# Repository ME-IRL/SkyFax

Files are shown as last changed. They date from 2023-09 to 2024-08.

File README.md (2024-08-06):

# SkyFax Modems

Fax and data modems built around Skyworks's [ISOModem chips](https://www.skyworksinc.com/en/Products/Modems-and-DAAs).

Current functional version is 4.1 (see 3.0 below):

Version 4.1 Assembled

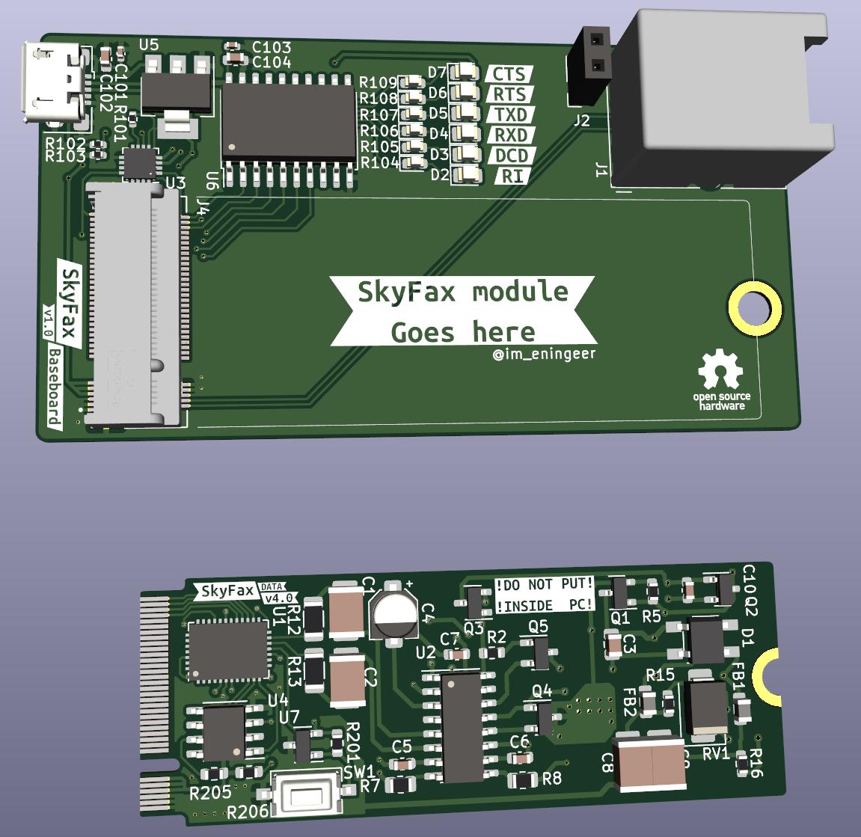
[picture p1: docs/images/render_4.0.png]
Revision 4.0 KiCad 3D Render


## Case

I've also designed and printed a case to go with it. The STL files can be found under [/case](/case). Or on [OnShape](https://cad.onshape.com/documents/ec3c126b0fcf528ada2a864d/w/a2689da35195e5fe9917eb13/e/6bc9b2e75f28a1d3ae68eb94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).

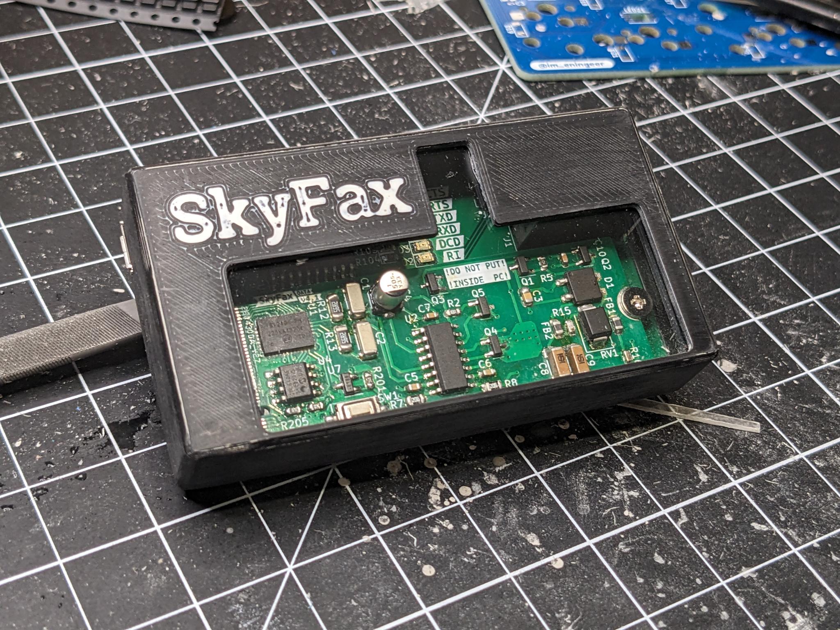
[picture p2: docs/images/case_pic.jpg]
case


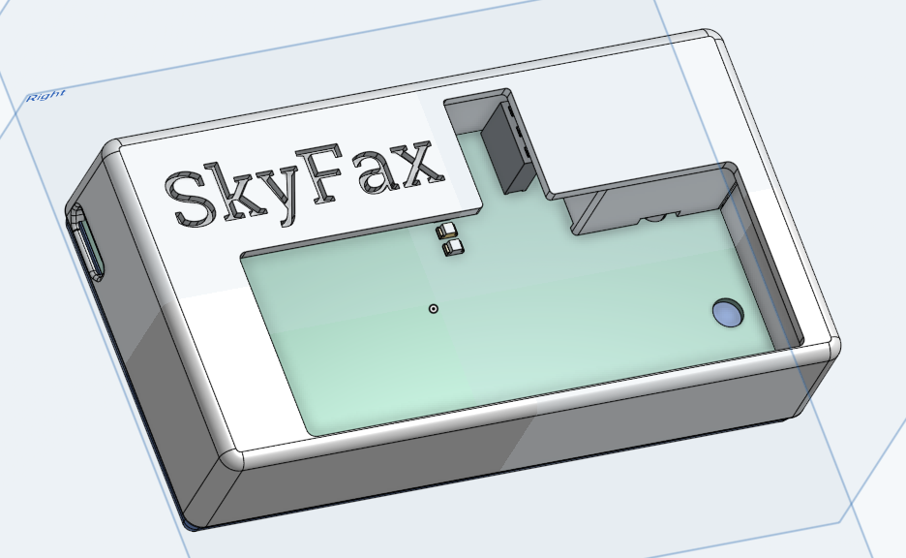
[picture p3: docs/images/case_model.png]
model


Version 3.0:

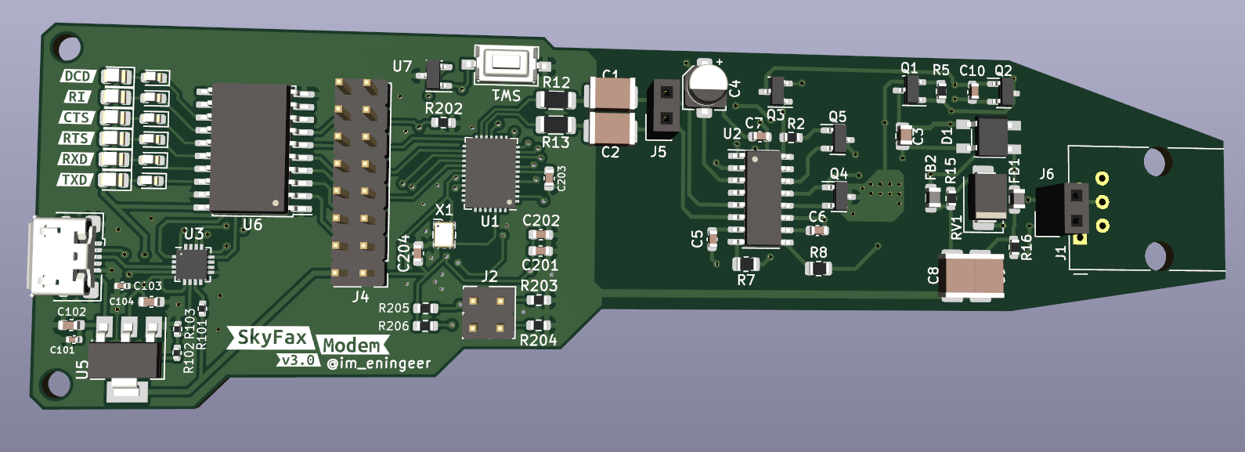
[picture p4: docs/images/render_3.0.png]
Revision 3.0 KiCad 3D Render


## Simple Line Simulator

If you don't have access to a working landline or a proper telephone line simulator two modems can be connected back to back directly.

There are [this](https://tldp.org/HOWTO/Modem-HOWTO-26.html) and [this](https://mattfife.com/?p=4765) pages, but I have found this circuit to work for me:

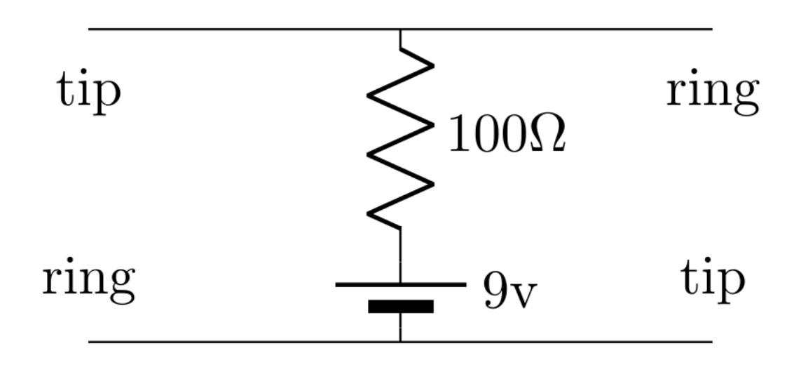
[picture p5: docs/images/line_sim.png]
Simple line simulator


The voltage and resistance can be tweaked to provide ~20mA of current with the modem/phone off-hook.

If you'd like the schematic or just have a PCB made for the line simulator, check out the [LineSim](/LineSim) project included in this repo.

Once hooked up, you want to disable the dialtone detection with the command `ATX3`. Then you can just dial with `ATDT` on one modem and answer with `ATA` on the other.

See [AN93](/docs/AN93.pdf) section 5.4 for details on all the AT commands supported.

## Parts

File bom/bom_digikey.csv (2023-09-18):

Reference | Value | Footprint | DIGIKEY | Qty
C1, C2 | 33pF | FaxCam:C_1808 | 732-8853520100071CT-ND | 2
C3 | 10nF | Capacitor_SMD:C_0805_2012Metric | 2679-C0805X7R251-103KNE-CT-ND | 1
C4 | 1uF | Capacitor_SMD:CP_Elec_4x3 | PCE3912CT-ND | 1
C5, C6, C102, C104, C201, C202, C204 | 0.1uF | Capacitor_SMD:C_0603_1608Metric | 2679-C0603X7R160-104MNE-CT-ND | 7
C7 | 2.7nF | Capacitor_SMD:C_0603_1608Metric | 2679-C0603X7R500-272MNE-CT-ND | 1
C8, C9 | 680pF | FaxCam:C_1808 | 4587-SCC1808X681K502TGCT-ND | 2
C10 | 0.01uF | Capacitor_SMD:C_0603_1608Metric | 2679-C0603X7R160-103MNE-CT-ND | 1
C101, C103 | 4.7uF | Capacitor_SMD:C_0402_1005Metric | 1276-1482-1-ND | 2
C203 | 0.22uF | Capacitor_SMD:C_0603_1608Metric | 1292-1420-1-ND | 1
D1 | HDS10M | FaxCam:Diodes_Inc_4-SMD | HDS10M-13DICT-ND | 1
D2-D7 | LED | LED_SMD:LED_0805_2012Metric | 160-1427-1-ND | 6
FB1, FB2 | FerriteBead_Small | Inductor_SMD:L_0805_2012Metric | 490-1040-1-ND | 2
J1 | RJ11/12 | Connector_RJ:RJ12_Amphenol_54601 | 609-5080-ND | 1
J2 | Audio | Connector_PinSocket_2.54mm:PinSocket_1x02_P2.54mm_Vertical |  | 1
J3 | USB_B_Micro | Connector_USB:USB_Micro-B_Amphenol_10118193-0001LF_Horizontal | 609-4616-1-ND | 1
J4 | M.2_B_Connector | SkyFax:AMPHENOL_MDT420B01001_2260 | MDT420B01001CT-ND | 1
J7 | M.2_B_Edge | SkyFax:M.2-B-KEY_2260 |  | 1
Q1, Q3 | Q_NPN_BEC | Package_TO_SOT_SMD:SOT-23-3 | MMBTA42LT1GOSCT-ND | 2
Q2 | Q_PNP_BEC | Package_TO_SOT_SMD:SOT-23-3 | MMBTA92LT1GOSCT-ND | 1
Q4, Q5 | Q_NPN_BEC | Package_TO_SOT_SMD:SOT-23-3 | MMBTA06LT1GOSCT-ND | 2
R1 | 1.07k | Resistor_SMD:R_2010_5025Metric | 13-RC2010FK-071K07LCT-ND | 1
R2 | 150 | Resistor_SMD:R_0603_1608Metric | 311-150HRCT-ND | 1
R3 | 3.65k | Resistor_SMD:R_2010_5025Metric | 13-RC2010FK-073K65LCT-ND | 1
R4 | 2.49k | Resistor_SMD:R_2010_5025Metric | 738-RMCF2010FT2K49CT-ND | 1
R5, R6 | 100k | Resistor_SMD:R_0603_1608Metric | A130103CT-ND | 2
R7, R8 | 20M | Resistor_SMD:R_0805_2012Metric | 13-RC0805JR-0720MLCT-ND | 2
R9 | 1M | Resistor_SMD:R_0603_1608Metric | A121559CT-ND | 1
R10 | 536 | Resistor_SMD:R_1210_3225Metric | 541-536AACT-ND | 1
R11 | 73.2 | Resistor_SMD:R_2010_5025Metric | 13-RC2010FK-0773R2LCT-ND | 1
R12, R13 | 56.2 | Resistor_SMD:R_1206_3216Metric | RNCP1206FTD56R2CT-ND | 2
R15, R16 | 0 | Resistor_SMD:R_0603_1608Metric | 36-5110CT-ND | 2
R101 | 1k | Resistor_SMD:R_0402_1005Metric | 311-1.0KJRCT-ND | 1
R102 | 22.1k | Resistor_SMD:R_0402_1005Metric | 311-22.1KLRCT-ND | 1
R103 | 47.5k | Resistor_SMD:R_0402_1005Metric | 311-47.5KLRCT-ND | 1
R104-R109 | 220 | LED_SMD:LED_0603_1608Metric | A130087CT-ND | 6
R201, R202, R205, R206 | 10k | Resistor_SMD:R_0603_1608Metric | RNCP0603FTD10K0CT-ND | 4
RV1 | ~ | Diode_SMD:D_SMB | P3100SBLRPCT-ND | 1
SW1 | SW_Push | Button_Switch_SMD:SW_Tactile_SPST_NO_Straight_CK_PTS636Sx25SMTRLFS | CKN12322-1-ND | 1
U1 | Si2494-A-FM | Package_DFN_QFN:QFN-38-1EP_5x7mm_P0.5mm_EP3.15x5.15mm | SI2494-A-FM-ND | 1
U2 | Si3018 | Package_SO:SOIC-16_3.9x9.9mm_P1.27mm | 336-4140-2-ND | 1
U3 | CP2102N-Axx-xQFN20 | Package_DFN_QFN:SiliconLabs_QFN-20-1EP_3x3mm_P0.5mm_EP1.8x1.8mm | 336-5886-1-ND | 1
U4 | 25LC640AT-E/SN | Package_SO:SOIC-8_3.9x4.9mm_P1.27mm | 25LC640AT-E/SNCT-ND | 1
U5 | AZ1117-3.3 | Package_TO_SOT_SMD:SOT-223-3_TabPin2 | AZ1117IH-3.3TRG1DICT-ND | 1
U6 | 74LCX541 | Package_SO:SOIC-20W_7.5x12.8mm_P1.27mm | 74LCX541WMXCT-ND | 1
U7 | DS1818 | Package_TO_SOT_SMD:SOT-23-3 | DS1818R-10+CT-ND | 1
X1 | ECS-2520MV-xxx-xx | Oscillator:Oscillator_SMD_ECS_2520MV-xxx-xx-4Pin_2.5x2.0mm | XC3186CT-ND | 1
Z1 | D_Zener | Diode_SMD:D_SOD-123 | BZT52C43-FDICT-ND | 1

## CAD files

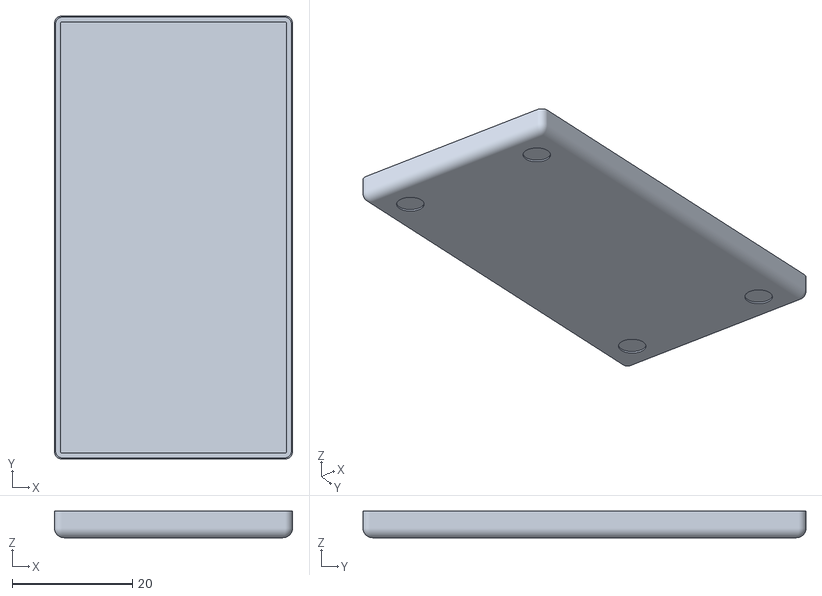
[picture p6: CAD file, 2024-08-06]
case/bottom.stl
39.5 x 73.6 x 4.40

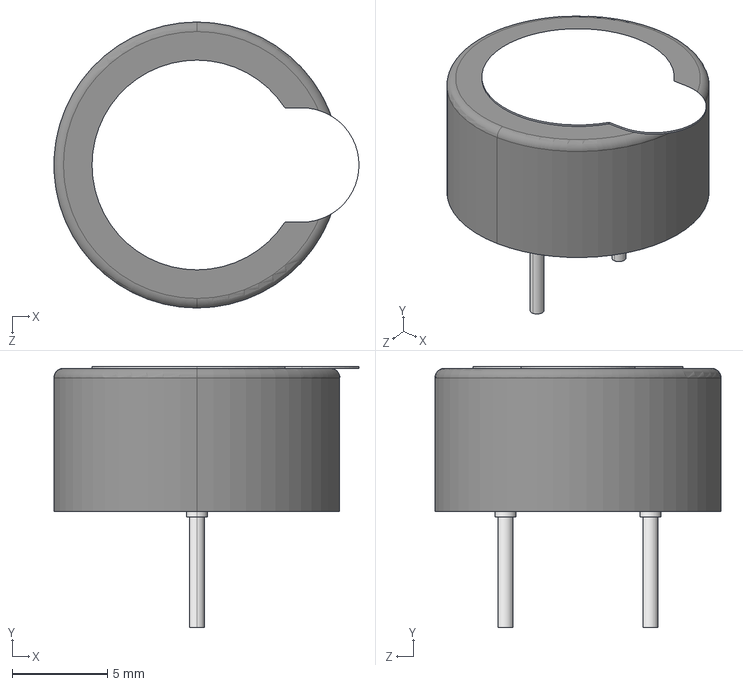
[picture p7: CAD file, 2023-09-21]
SoundCard/3dmodels/CUI_DEVICES_CVS-1508.step
16.0 x 13.7 x 15.0 mm

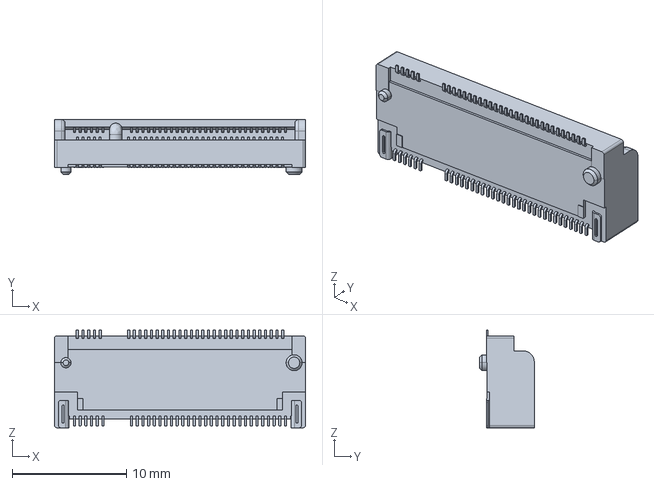
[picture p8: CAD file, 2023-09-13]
3dmodel/mdt420b0x001_c3d.stp
22.0 x 4.80 x 8.55 mm

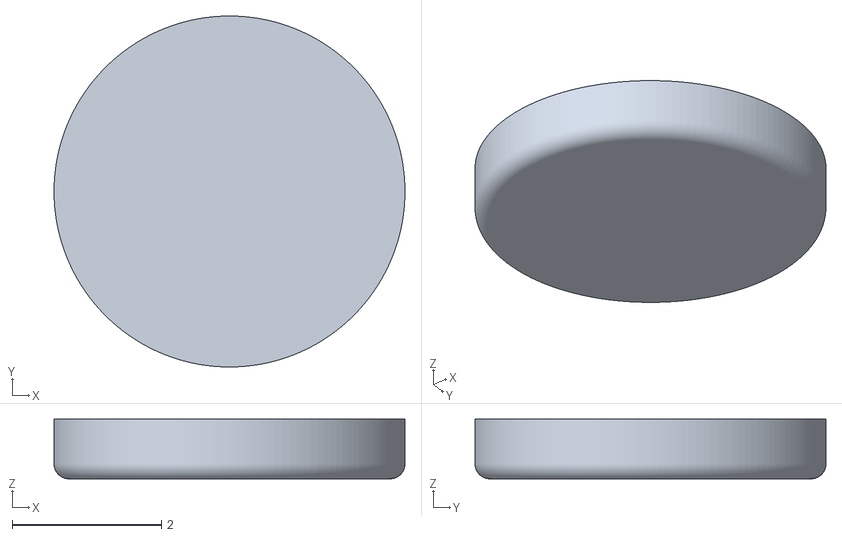
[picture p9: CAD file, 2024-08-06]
case/feet.stl
4.70 x 4.70 x 0.8

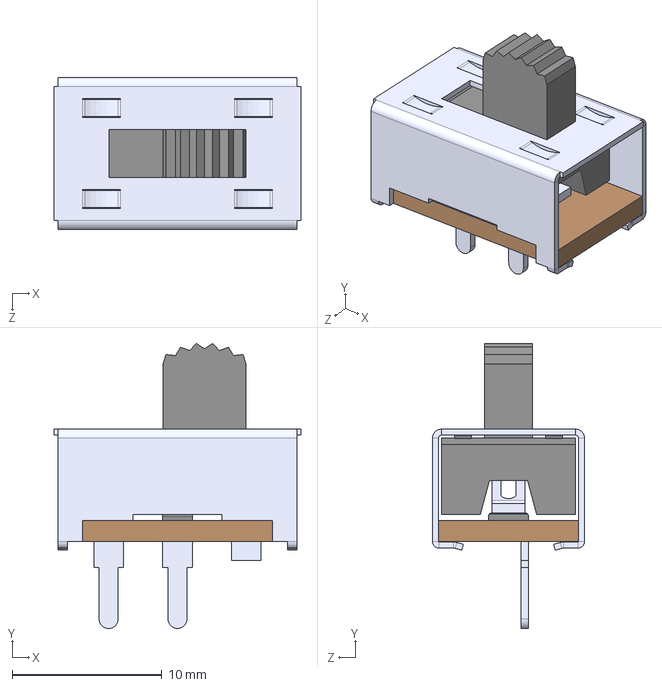
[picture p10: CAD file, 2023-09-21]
LineSim/3dmodels/GF-123-0054.step
16.5 x 19.0 x 10.2 mm

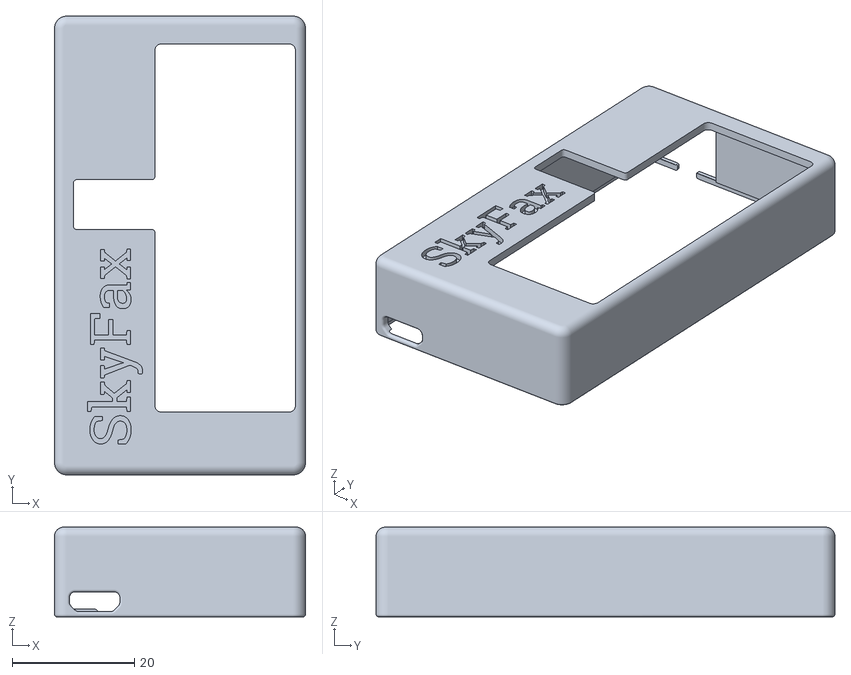
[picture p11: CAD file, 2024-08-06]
case/top.stl
41.1 x 75.2 x 14.7

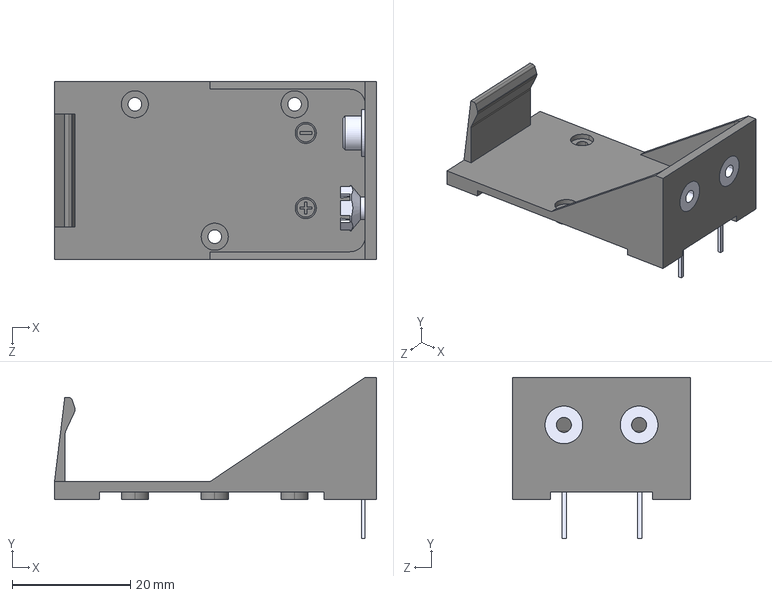
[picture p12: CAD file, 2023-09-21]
LineSim/3dmodels/BH9VPC.step
54.4 x 27.2 x 30.0 mm

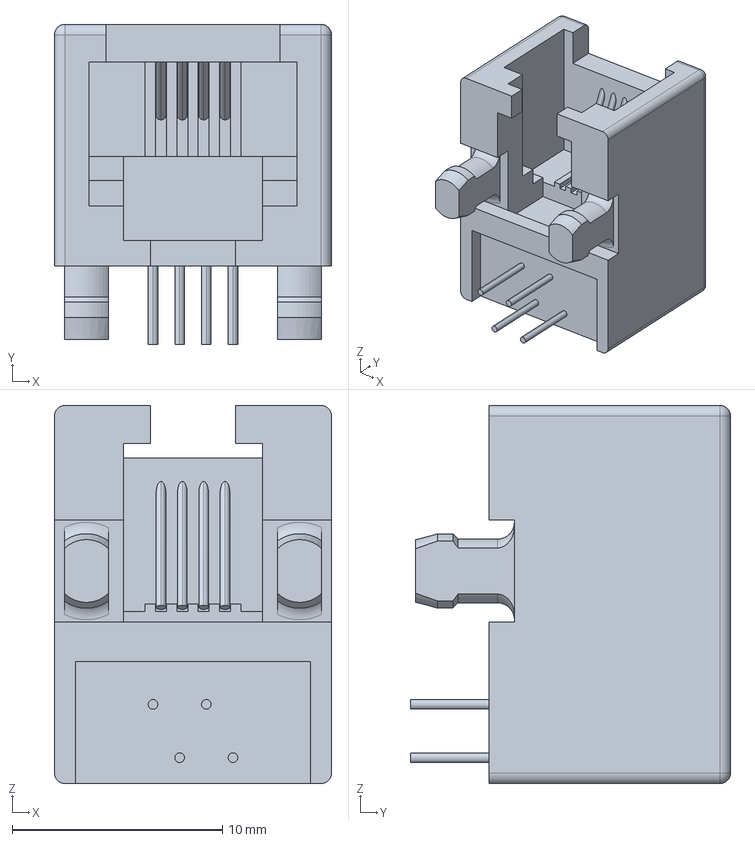
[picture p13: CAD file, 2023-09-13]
3dmodel/54601-906002WPLFc.stp
13.2 x 15.2 x 18.0 mm

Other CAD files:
LineSim/3dmodels/54601-906001.step
SoundCard/3dmodels/CUI_DEVICES_CVS-1508.STL

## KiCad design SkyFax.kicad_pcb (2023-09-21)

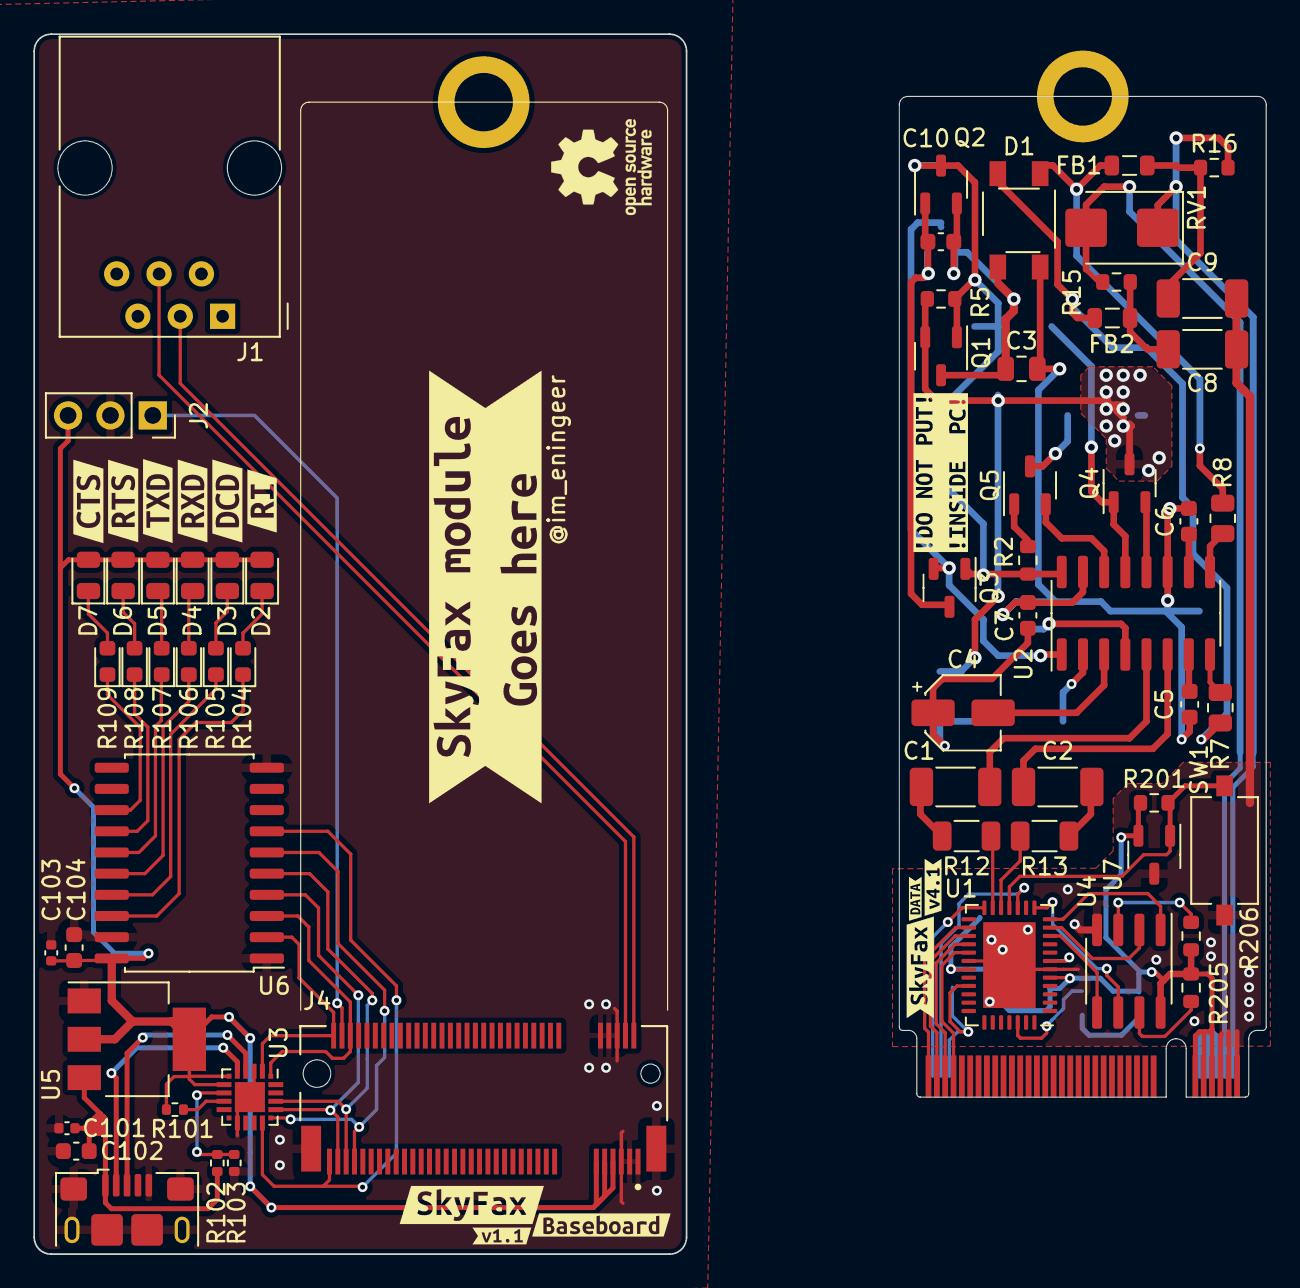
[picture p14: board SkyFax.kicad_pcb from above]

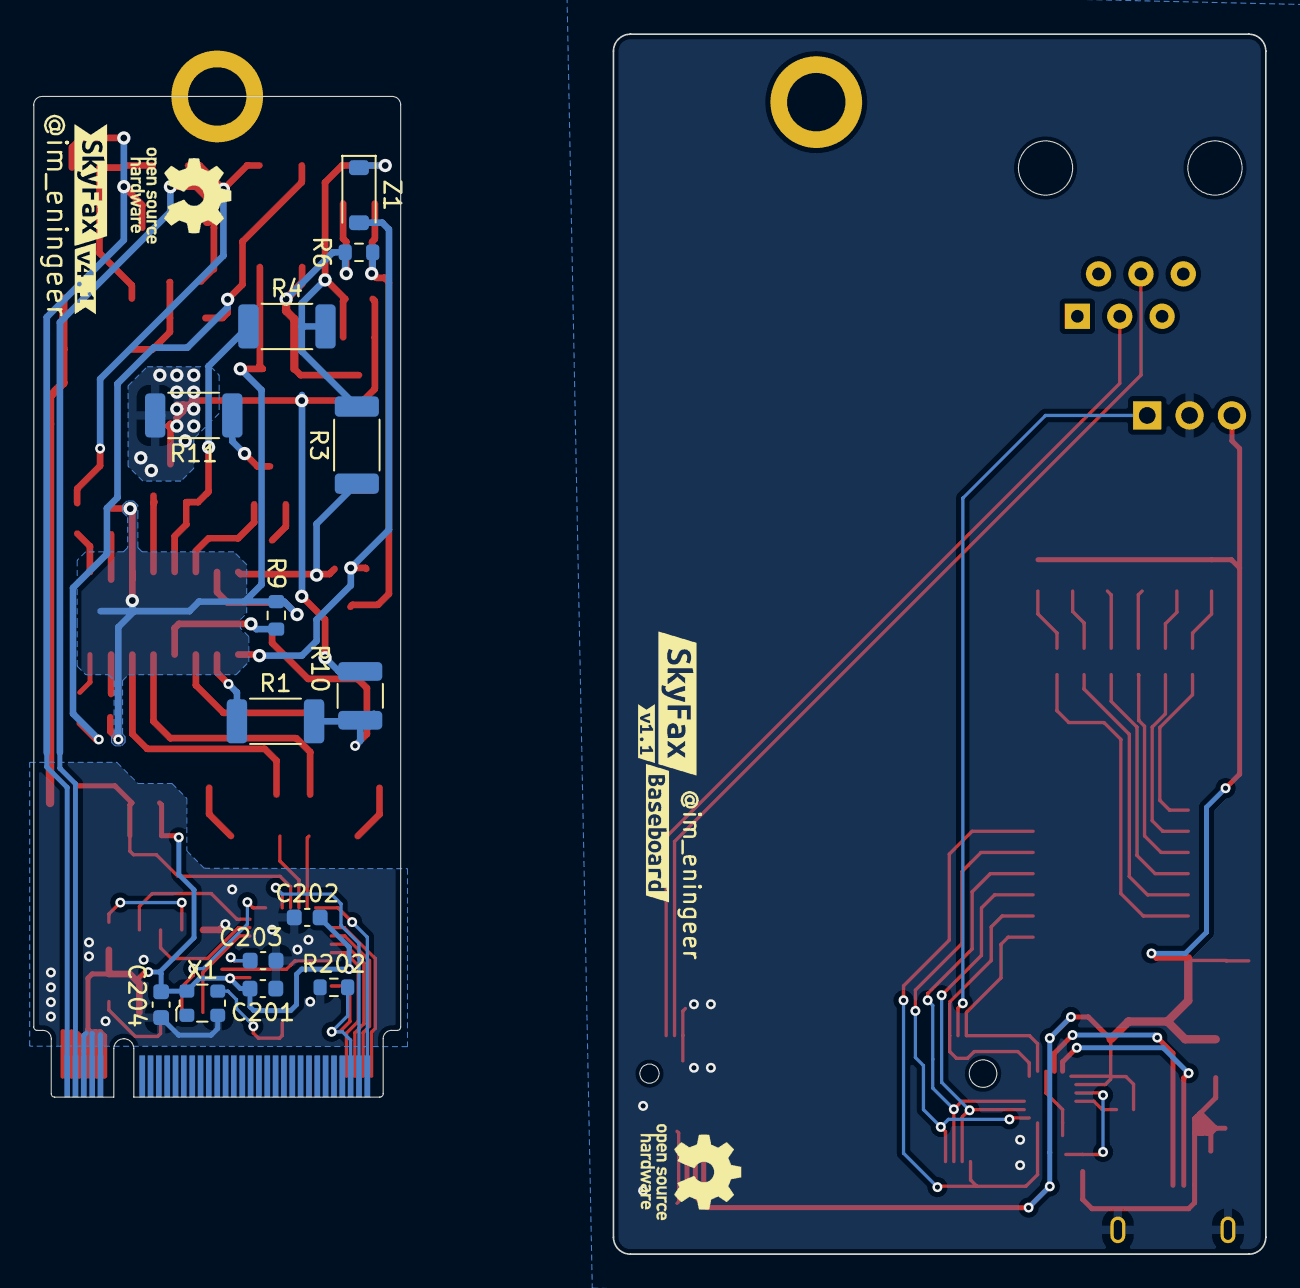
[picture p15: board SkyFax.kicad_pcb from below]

Board: 2 copper layers, 73.9 x 73.2 mm, 95 parts (19 on the bottom side), 76 nets.

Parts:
C1, C2: 33pF; C_1808
C3: 10nF; C_0805_2012Metric
C4: 1uF; CP_Elec_4x3
C5, C6, C102, C104, C201, C202, C204: 0.1uF; C_0603_1608Metric
C7: 2.7nF; C_0603_1608Metric
C8, C9: 680pF; C_1808
C10: 0.01uF; C_0603_1608Metric
C101, C103: 4.7uF; C_0402_1005Metric
C203: 0.22uF; C_0603_1608Metric
D1: HDS10M; Diodes_Inc_4-SMD
D2, D3, D4, D5, D6, D7: LED; LED_0805_2012Metric
FB1, FB2: FerriteBead_Small; L_0805_2012Metric
J1: RJ11/12; RJ12_Amphenol_54601
J2: Audio; PinSocket_1x03_P2.54mm_Vertical
J3: USB_B_Micro; USB_Micro-B_Amphenol_10118193-0001LF_Horizontal
J4: M.2_B_Connector; AMPHENOL_MDT420B01001_2260
J7: M.2_B_Edge; M.2-B-KEY_2260
Q1, Q3, Q4, Q5: Q_NPN_BEC; SOT-23-3
Q2: Q_PNP_BEC; SOT-23-3
R1: 1.07k; R_2010_5025Metric
R2: 150; R_0603_1608Metric
R3: 3.65k; R_2010_5025Metric
R4: 2.49k; R_2010_5025Metric
R5, R6: 100k; R_0603_1608Metric
R7, R8: 20M; R_0805_2012Metric
R9: 1M; R_0603_1608Metric
R10: 536; R_1210_3225Metric
R11: 73.2; R_2010_5025Metric
R12, R13: 56.2; R_1206_3216Metric
R15, R16: 0; R_0603_1608Metric
R101: 1k; R_0402_1005Metric
R102: 22.1k; R_0402_1005Metric
R103: 47.5k; R_0402_1005Metric
R104, R105, R106, R107, R108, R109: 220; LED_0603_1608Metric
R201, R202, R205, R206: 10k; R_0603_1608Metric
RV1: D_SMB
SW1: SW_Push; SW_Tactile_SPST_NO_Straight_CK_PTS636Sx25SMTRLFS
U1: Si2494-A-FM; QFN-38-1EP_5x7mm_P0.5mm_EP3.15x5.15mm
U2: Si3018; SOIC-16_3.9x9.9mm_P1.27mm
U3: CP2102N-Axx-xQFN20; SiliconLabs_QFN-20-1EP_3x3mm_P0.5mm_EP1.8x1.8mm
U4: 25LC640AT-E/SN; SOIC-8_3.9x4.9mm_P1.27mm
U5: AZ1117-3.3; SOT-223-3_TabPin2
U6: 74LCX541; SOIC-20W_7.5x12.8mm_P1.27mm
U7: DS1818; SOT-23-3
X1: ECS-2520MV-xxx-xx; Oscillator_SMD_ECS_2520MV-xxx-xx-4Pin_2.5x2.0mm
Z1: D_Zener; D_SOD-123
kibuzzard-650CCF10: G***; kibuzzard-650CCF10
kibuzzard-650CCF19: G***; kibuzzard-650CCF19
kibuzzard-6508DE31: G***; kibuzzard-6508DE31
kibuzzard-6508DE41: G***; kibuzzard-6508DE41
kibuzzard-650110F6: G***; kibuzzard-650110F6
kibuzzard-650111BC: G***; kibuzzard-650111BC
kibuzzard-650123DF: G***; kibuzzard-650123DF
kibuzzard-650125E8: G***; kibuzzard-650125E8
kibuzzard-6501311A: G***; kibuzzard-6501311A
kibuzzard-6501314E: G***; kibuzzard-6501314E
kibuzzard-6501315C: G***; kibuzzard-6501315C
kibuzzard-6501316E: G***; kibuzzard-6501316E
kibuzzard-6501317F: G***; kibuzzard-6501317F
kibuzzard-6501337B, kibuzzard-6501337B#2: G***; kibuzzard-6501337B
kibuzzard-65013126: G***; kibuzzard-65013126
kibuzzard-65013388, kibuzzard-65013388#2: G***; kibuzzard-65013388
kibuzzard-65013408: G***; kibuzzard-65013408

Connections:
+3V3: C103.2, C104.2, C201.2, C202.2, C204.2, D2.2 (A), D3.2 (A), D4.2 (A), D5.2 (A), D6.2 (A), D7.2 (A), J2.3, J4.7, J4.9, J4.11, J7.7, J7.9, J7.11, R101.1, R201.1, R205.1, R206.1, U1.5 (VDD), U1.26 (VDD), U3.6 (VDD), U3.7 (VREGIN), U4.8 (VCC), U5.2 (VO), U6.20 (VCC), U7.2 (VCC), X1.4 (VDD)
/MOD_AOUT: J7.72, U1.15 (AOUT)
/MOD_CTS: J7.75, U1.21 (nCTS_SCLKC_nCS)
/MOD_DCD: J7.70, R202.1, U1.28 (nDCD_D6)
/MOD_RI: J7.74, U1.19 (nRI)
/MOD_RING: J7.4, R15.2, RV1.2
/MOD_RTS: J7.69, U1.24 (nRTS_nSS_D7)
/MOD_RXD: J7.73, U1.22 (RXD_MISO_nRD)
/MOD_TIP: J7.2, R16.2, RV1.1
/MOD_TXD: J7.71, U1.23 (TXD_MOSI_nWR)
/SI2494/C1A: R12.1, U1.18 (C1A)
/SI2494/C2A: R13.1, U1.17 (C2A)
/SI2494/EECLK: U1.13 (EECLK), U4.6 (SCK)
/SI2494/EECS: U1.12 (nEECS), U4.1 (~CS)
/SI2494/EESDI: U1.10 (EESDI), U4.5 (MOSI)
/SI2494/EESDO: U1.11 (EESDO), U4.2 (MISO)
/SI2494/RST: R201.2, SW1.2, U1.16 (nRST), U7.1 (RST)
/SI3018/C1A: C1.1, U2.5 (C1B)
/SI3018/C2A: C2.1, U2.6 (C2B)
/USB_AOUT: J2.1, J4.72
/USB_CTS: J4.75, U3.15 (~CTS), U6.7 (A5)
/USB_DCD: J4.70, U3.1 (RS485/GPIO.1), U6.3 (A1)
/USB_RI: J4.74, U3.2 (CLK/GPIO.0), U6.2 (A0)
/USB_RING: J1.4, J4.4
/USB_RTS: J4.69, U3.16 (~RTS), U6.6 (A4)
/USB_RXD: J4.73, U3.17 (RXD), U6.4 (A2)
/USB_TIP: J1.3, J4.2
/USB_TXD: J4.71, U3.18 (TXD), U6.5 (A3)
GND: C8.2, C9.2, C101.1, C102.1, C103.1, C104.1, C201.1, C202.1, C203.1, C204.1, J2.2, J3.5 (GND), J3.6 (Shield), J4.1, J4.3, J4.5, J4.6, J4.8, J4.10, J4.S1 (SHIELD), J4.S2 (SHIELD), J7.1, J7.3, J7.5, J7.6, J7.8, J7.10, R103.2, R202.2, SW1.1, U1.6 (GND), U1.25 (GND), U1.39 (EP), U3.3 (GND), U3.12 (GND), U3.21 (GND), U4.4 (GND), U5.1 (GND), U6.1 (G1), U6.10 (GND), U6.19 (G2), U7.3 (GND), X1.2 (GND)
GND1: C3.2, C5.2, C6.2, C7.1, D1.3 (-), R9.1, U2.11 (SC), U2.15 (IGND)
unnamed: C1.2, R12.2
unnamed: C2.2, R13.2
unnamed: C4.1, C7.2, R1.2, R10.1
unnamed: C8.1, FB2.2, R15.1
unnamed: C9.1, FB1.2, R16.1
unnamed: C3.1, C10.1, D1.1 (+), Q1.3 (C), Q2.2 (E), R6.1
unnamed: D1.2, FB2.1, R7.1
unnamed: D1.4, FB1.1, R8.2
unnamed: D2.1 (K), R104.2
unnamed: D3.1 (K), R105.2
unnamed: D4.1 (K), R106.2
unnamed: D5.1 (K), R107.2
unnamed: D6.1 (K), R108.2
unnamed: D7.1 (K), R109.2
unnamed: J3.3 (D+), U3.4 (D+)
unnamed: J3.2 (D-), U3.5 (D-)
unnamed: Q1.1 (B), Q2.3 (C), R3.2, R4.2, R5.1, Z1.1 (K)
unnamed: Q1.2 (E), Q4.3 (C), R5.2, R10.2, R11.2
unnamed: C10.2, Q2.1 (B), Q3.3 (C), R6.2
unnamed: Q3.1 (B), R2.1, R3.1, U2.16 (DCT2)
unnamed: Q3.2 (E), U2.1 (QE), Z1.2 (A)
unnamed: Q4.1 (B), R4.1, U2.13 (QB)
unnamed: Q4.2 (E), U2.12 (QE2)
unnamed: Q5.1 (B), R2.2
unnamed: Q5.3 (C), R11.1
unnamed: Q5.2 (E), U2.14 (DCT3)
unnamed: U1.36 (CLKIN_XTAL1), X1.3 (OUT)
unnamed: C203.2, U1.7 (VREG)
unnamed: R1.1, U2.2 (DCT)
unnamed: R9.2, U2.4 (IB)
unnamed: R7.2, U2.8 (RNG1)
unnamed: R8.1, U2.9 (RNG2)
unnamed: C4.2, U2.3 (RX)
unnamed: C6.1, U2.10 (VREG2)
unnamed: C5.1, U2.7 (VREG)
unnamed: R102.2, R103.1, U3.8 (VBUS)
unnamed: R101.2, U3.9 (~RST)
unnamed: R205.2, U4.7 (~HOLD)
unnamed: R206.2, U4.3 (~WP)
unnamed: R104.1, U6.18 (Y0)
unnamed: R105.1, U6.17 (Y1)
unnamed: R106.1, U6.16 (Y2)
unnamed: R107.1, U6.15 (Y3)
unnamed: R108.1, U6.14 (Y4)
unnamed: R109.1, U6.13 (Y5)
VBUS: C101.2, C102.2, J3.1 (VBUS), R102.1, U5.3 (VI)

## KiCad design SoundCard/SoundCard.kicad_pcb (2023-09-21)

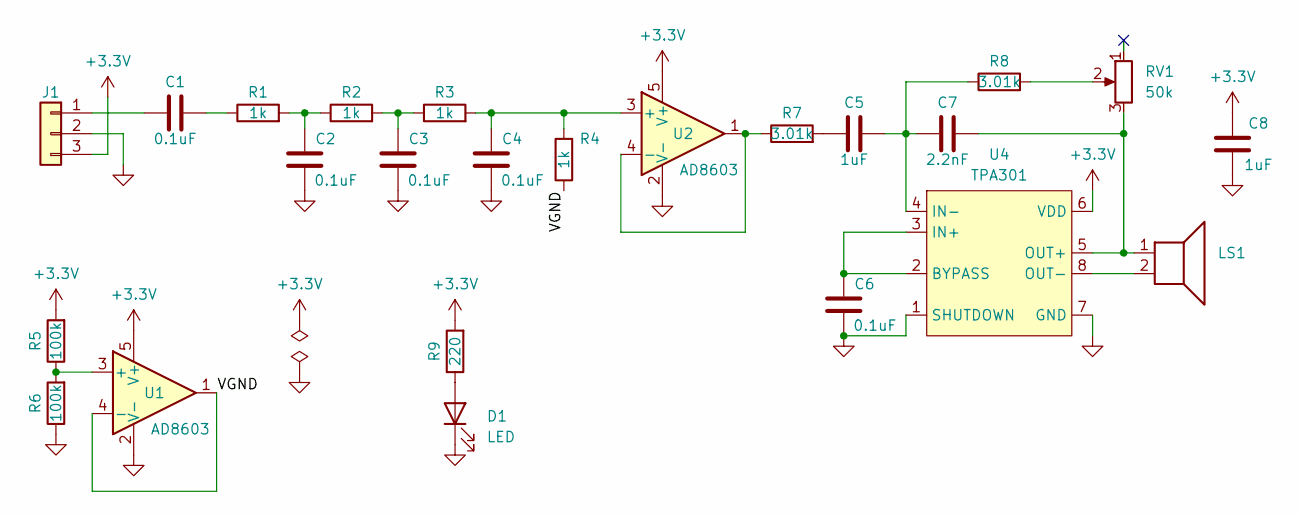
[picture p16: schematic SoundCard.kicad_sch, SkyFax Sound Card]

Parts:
C1, C2, C3, C4, C6: 0.1uF; C_0402_1005Metric; DIGIKEY 1276-1043-1-ND
C5, C8: 1uF; C_0402_1005Metric; DIGIKEY 1276-1076-1-ND
C7: 2.2nF; C_0402_1005Metric; DIGIKEY 490-GCM155R71H222KA37JCT-ND
D1: LED; LED_0805_2012Metric; DIGIKEY 160-1427-1-ND
J1: Conn_01x03; PinHeader_1x03_P2.54mm_Vertical
LS1: Speaker; PC_Speaker_15.0mm; DIGIKEY 102-2498-ND
R1, R2, R3, R4: 1k; R_0402_1005Metric; DIGIKEY MCS0402-1.00K-CFCT-ND
R5, R6: 100k; R_0402_1005Metric; DIGIKEY YAG2304CT-ND
R7, R8: 3.01k; R_0402_1005Metric; DIGIKEY 311-3.01KLRCT-ND
R9: 220; R_0402_1005Metric; DIGIKEY A130087CT-ND
RV1: 50k; Potentiometer_Bourns_TC33X_Vertical; DIGIKEY 118-TC33X-2-503GCT-ND
U1, U2: AD8603; TSOT-23-5; DIGIKEY AD8603AUJZ-REELCT-ND
U4: TPA301; SOIC-8_3.9x4.9mm_P1.27mm; DIGIKEY 296-1945-1-ND

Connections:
+3.3V: C8.2, J1.3, R5.2, R9.2, U1.5 (V+), U2.5 (V+), U4.6 (VDD)
/VGND: R4.1, U1.1, U1.4 (-)
GND: C2.2, C3.2, C4.2, C6.2, C8.1, D1.1 (K), J1.2, R6.1, U1.2 (V-), U2.2 (V-), U4.1 (SHUTDOWN), U4.7 (GND)
unnamed: C1.2, R1.1
unnamed: C2.1, R1.2, R2.1
unnamed: C3.1, R2.2, R3.1
unnamed: C5.1, R7.2
unnamed: D1.2 (A), R9.1
unnamed: C1.1, J1.1
unnamed: R8.2, RV1.2
unnamed: R5.1, R6.2, U1.3 (+)
unnamed: C4.1, R3.2, R4.2, U2.3 (+)
unnamed: R7.1, U2.1, U2.4 (-)
unnamed: C6.1, U4.2 (BYPASS), U4.3 (IN+)
unnamed: C5.2, C7.1, R8.1, U4.4 (IN-)
unnamed: C7.2, LS1.1, RV1.3, U4.5 (OUT+)
unnamed: LS1.2, U4.8 (OUT-)

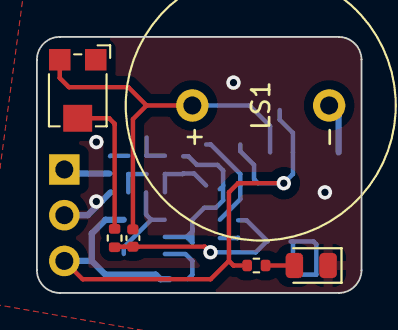
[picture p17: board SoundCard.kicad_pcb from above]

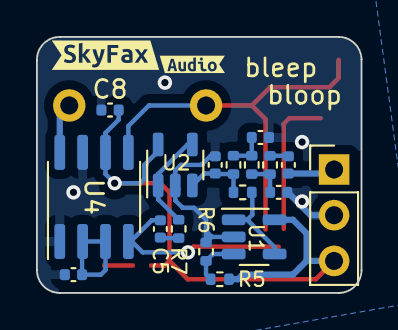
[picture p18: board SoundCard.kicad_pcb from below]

Board: 2 copper layers, 18.0 x 14.2 mm, 26 parts (20 on the bottom side), 17 nets.

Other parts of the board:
kibuzzard-650CC8A2: G***; kibuzzard-650CC8A2
kibuzzard-650CC8CA: G***; kibuzzard-650CC8CA

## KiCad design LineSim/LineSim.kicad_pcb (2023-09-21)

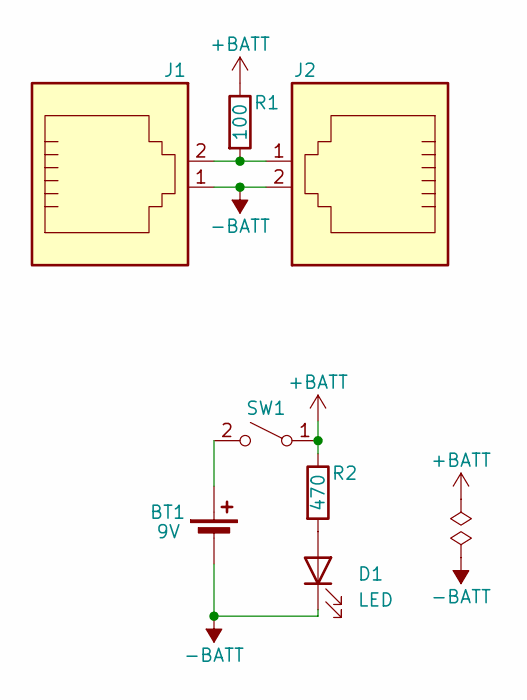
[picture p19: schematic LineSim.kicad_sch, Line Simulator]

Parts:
BT1: 9V; BAT_BH9VPC; DIGIKEY BH9V-PC-ND
D1: LED; LED_D5.0mm; DIGIKEY 754-1264-ND
J1, J2: RJ11; DIGIKEY 609-5080-ND
R1: 100; R_Axial_DIN0207_L6.3mm_D2.5mm_P7.62mm_Horizontal; DIGIKEY CF14JT100RCT-ND
R2: 470; R_Axial_DIN0207_L6.3mm_D2.5mm_P7.62mm_Horizontal; DIGIKEY CF14JT470RCT-ND
SW1: SW_SPST; SW_GF-123-0054; DIGIKEY CWI333-ND

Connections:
+BATT: R1.1, R2.1, SW1.1 (A)
-BATT: BT1.2 (-), D1.1 (K), J1.1, J2.2
unnamed: BT1.1 (+), SW1.2 (B)
unnamed: D1.2 (A), R2.2
unnamed: J1.2, J2.1, R1.2

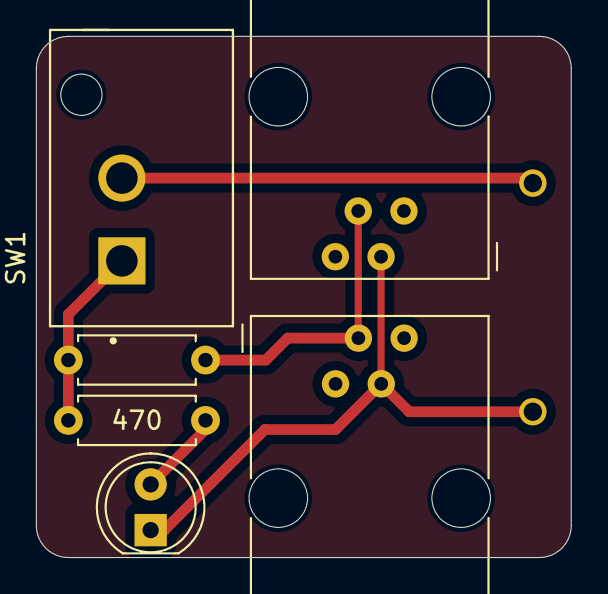
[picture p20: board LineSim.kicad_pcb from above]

Board: 4 copper layers, 29.7 x 29.0 mm, 7 parts (1 on the bottom side), 5 nets.

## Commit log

2023-07-04 Initial.
    Schematics v1.0
    Working on PCB layout
    [SkyFax.kicad_pcb, SkyFax.kicad_sch]
2023-07-04 Sent to fab v1.0
    [SkyFax.kicad_pcb, SkyFax.kicad_sch]
2023-07-16 Version 2.0 Schematics
    [SkyFax.kicad_sch]
2023-07-17 Layout v1.9 (not finished)
    [SkyFax.kicad_pcb, SkyFax.kicad_sch]
2023-08-18 Sent to fab v2.0
    [SkyFax.kicad_pcb, SkyFax.kicad_sch]
2023-09-03 Schematics v3.0
    [SkyFax.kicad_sch, si2494.kicad_sch, si3018.kicad_sch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]
2023-09-03 Sent to fab v3.0
    [SkyFax.kicad_pcb, SkyFax.kicad_sch, si2494.kicad_sch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]
2023-09-11 Version 3.0 minor BOM changes
    [SkyFax.kicad_pcb, SkyFax.kicad_sch]
2023-09-11 Version 3.0 ERC/DRC fixes
    [SkyFax.kicad_pcb, SkyFax.kicad_sch, si2494.kicad_sch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]
2023-09-11 [3.0*] Fix 3D models
    [SkyFax.kicad_pcb]
2023-09-11 [3.0] BOM + Gerbers
    [SkyFax.kicad_pcb]
2023-09-13 [4.0] M.2 Module. Sent to fab
    [54601-906002WPLFc.stp, SkyFax.kicad_pcb, SkyFax.kicad_sch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]
2023-09-18 [4.1] Fix minor layout + BoM issue
    X1, C204, R202 were too close to M.2 connector edge
    Didn't realize one of the components were not included in the BoM (Q1,Q3)
    [SkyFax.kicad_pcb, bom_digikey.csv]
2023-09-21 [docs] Add line simulator circuit
2023-09-21 [docs] Fix line_sim circuit
2023-09-21 [line-sim] Line simulator KiCad
    [54601-906001.step, BH9VPC.step, GF-123-0054.step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]
2023-09-21 [4.2] Sound card
    [CUI_DEVICES_CVS-1508.STL, CUI_DEVICES_CVS-1508.step, SkyFax.kicad_pcb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]
2024-08-06 Add case and photos
    [bottom.stl, feet.stl, top.stl]
